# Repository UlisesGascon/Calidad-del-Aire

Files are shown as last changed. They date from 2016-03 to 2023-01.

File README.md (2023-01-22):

<h2 align="center">:warning: This repository is not longer maintained :warning:</h2>

# Calidad-del-Aire
Sistema para controlar la calidad del aire usando Arduino y los sensores MQ(2-9, y 135), AM2302 y DHT22. Los datos se exportan en formato .json vía comunicación serial

### Ejemplos de uso

- **[Calidad del Aire con Firebase](https://github.com/UlisesGascon/Calidad-del-Aire-con-Firebase)**
Repositorio que muestra como se pueden exportar estos datos usando Node.js para posteriormente almacenarlos en Firebase. Múltiples usuarios pueden consultar los datos en tiempo real usando Websockets. [Demo](https://calidaddelaire.firebaseio.com/)

### Contenedor (caja)

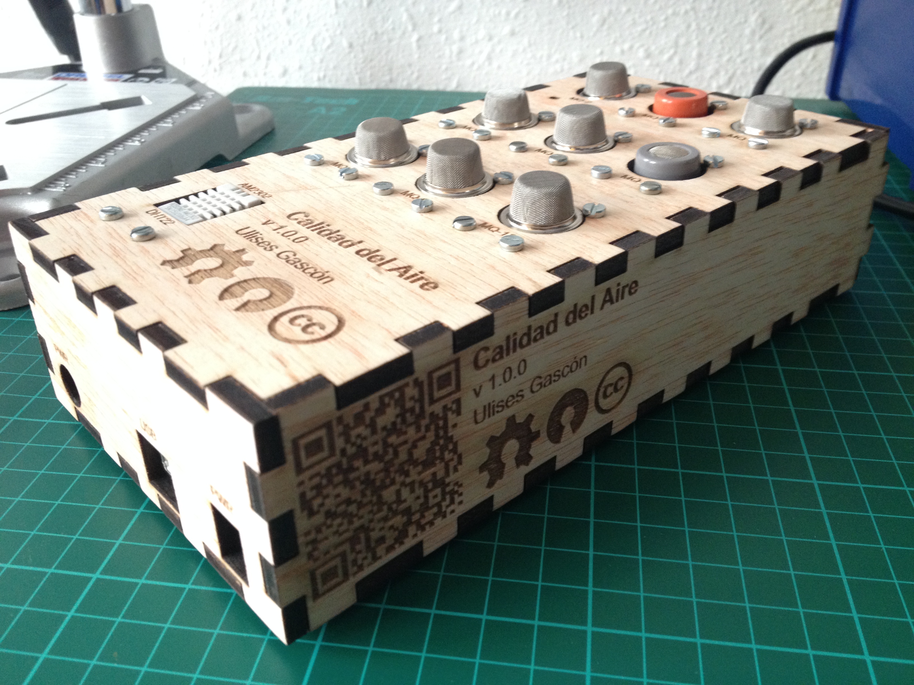
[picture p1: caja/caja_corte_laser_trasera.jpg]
caja


**Diseño impresión 3D**

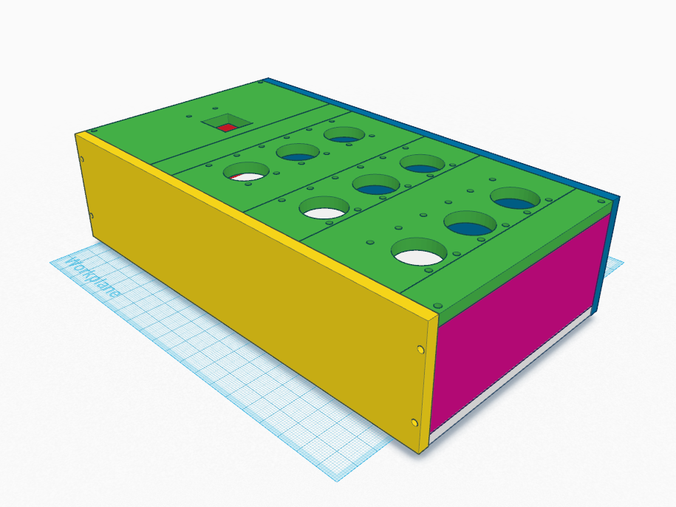
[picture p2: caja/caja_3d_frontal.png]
caja


- [Formato .STL](caja/caja_design.png)
- [Formato .OBJ](caja/caja_design.png)

**Diseño Corte Laser**

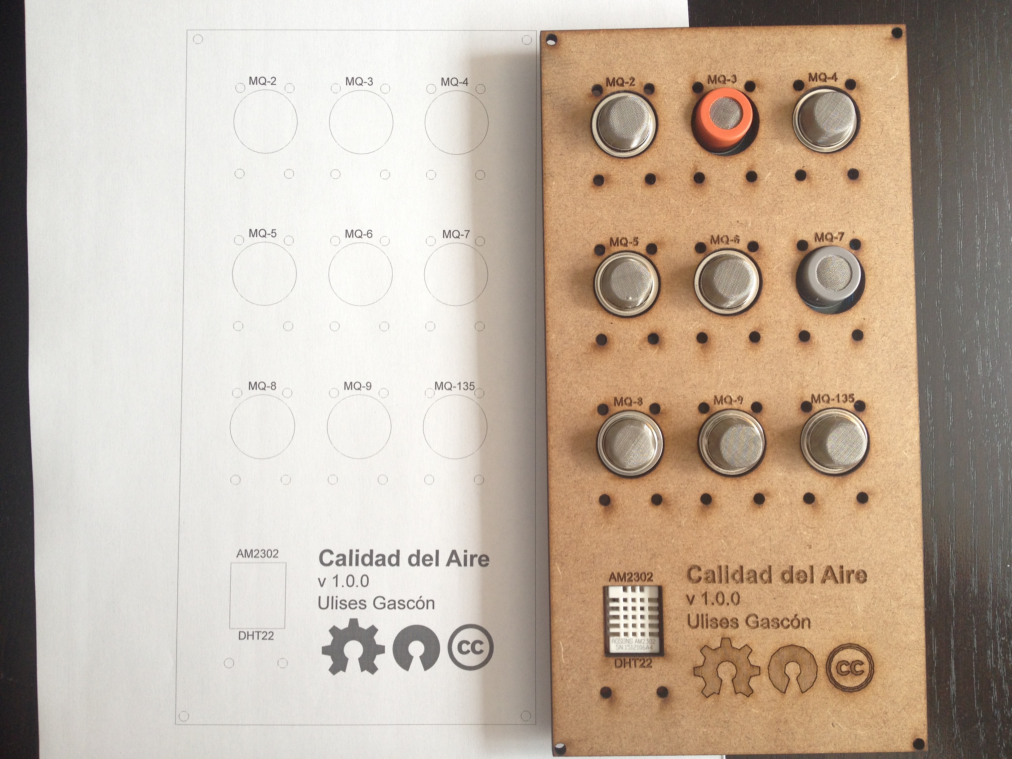
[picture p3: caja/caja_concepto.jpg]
caja


- [Formato .DXF](caja/caja_design.dxf)
- [Formato .SVG](caja/caja_design.svg)
- [Formato .PNG](caja/caja_design.png)
- [Formato .PDF](caja/caja_design.pdf)

### Conexiones

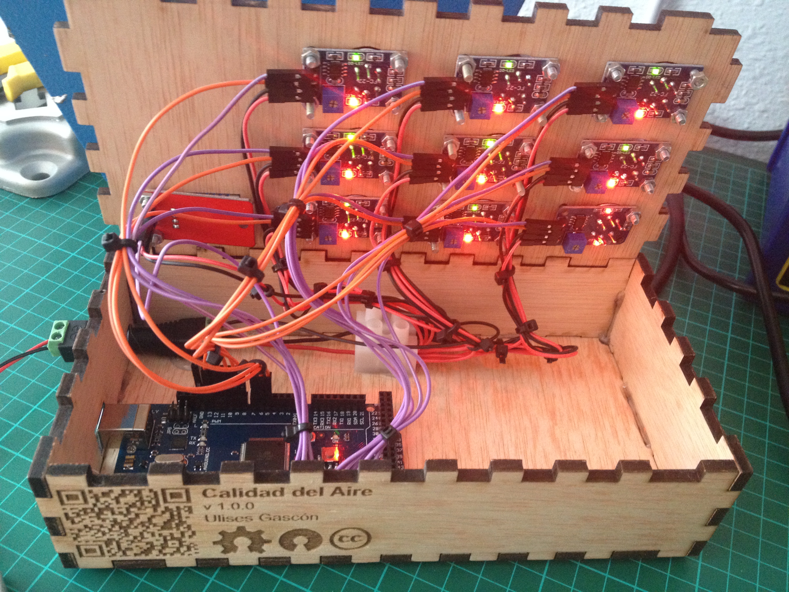
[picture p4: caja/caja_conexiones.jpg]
caja


**Alimentación**

- Alimentación externa (5v - 3A). Todos los sensores se conectan a la alimentación externa.

- GND del Arduino y GND de la fuente externa se conectan entre sí.

- IMPORTANTE: 5v (fuente de alimentación) y 5v (Arduino) NO se conectan entre sí.

**Analógicas**

- MQ-2 -> A13
- MQ-3 -> A12
- MQ-4 -> A11
- MQ-5 -> A10
- MQ-6 -> A9
- MQ-7 -> A8
- MQ-8 -> A7
- MQ-9 -> A6
- MQ-135 -> A5

**Digitales**

- MQ-2 -> 13
- MQ-3 -> 12
- MQ-4 -> 11
- MQ-5 -> 10
- MQ-6 -> 9
- MQ-7 -> 8
- MQ-8 -> 7
- MQ-9 -> 6
- MQ-135 -> 5
- AM2302/DHT22 -> 4

### Datos (formato [JSON](https://www.wikiwand.com/es/JSON))

Ejemplo de los datos que esperamos recibir vía puerto serial

```json
{
	"amoniaco": {
		"valido": true,
		"valor": 0.06,
		"unidad": "ppm",
		"descripcion": "Amoníaco",
		"formulaQuimica": ["NH3"],
		"umbralAlcanzado": false,
		"voltaje": 0.23,
		"resistencia": 20312.50,
		"valorAnalogico": 48,
		"sensor": "MQ-135"
	},
	"dioxidoDeCarbono": {
		"valido": true,
		"valor": 0.06,
		"unidad": "ppm",
		"descripcion": "Dióxido de carbono",
		"formulaQuimica": ["CO2"],
		"umbralAlcanzado": false,
		"voltaje": 0.23,
		"resistencia": 20312.50,
		"valorAnalogico": 48,
		"sensor": "MQ-135"
	},
	"oxidosDeNitrogeno": {
		"valido": true,
		"valor": 0.06,
		"unidad": "ppm",
		"descripcion": "Óxidos de nitrógeno (Óxido nitroso, Óxido nítrico, Anhídrido nitroso, Tetraóxido de nitrógeno, Peróxido nítrico, Anhídrido nítrico)",
		"formulaQuimica": ["NOx", "N2O", "NO", "N2O3", "N2O4", "NO2", "N2O5"],
		"umbralAlcanzado": false,
		"voltaje": 0.23,
		"resistencia": 20312.50,
		"valorAnalogico": 48,
		"sensor": "MQ-135"
	},
	"hidrogeno": {
		"valido": true,
		"valor": 0.09,
		"unidad": "ppm",
		"descripcion": "Hidrógeno",
		"formulaQuimica": ["H2"],
		"umbralAlcanzado": false,
		"voltaje": 0.32,
		"resistencia": 14738.46,
		"valorAnalogico": 65,
		"sensor": "MQ-8"
	},
	"monoxidoDeCarbono": {
		"valido": true,
		"valor": 0.09,
		"unidad": "ppm",
		"descripcion": "Monóxido de Carbono",
		"formulaQuimica": ["CO"],
		"umbralAlcanzado": false,
		"voltaje": 0.31,
		"resistencia": 15238.09,
		"valorAnalogico": 63,
		"sensor": "MQ-7"
	},
	"propano": {
		"valido": true,
		"valor": 0.15,
		"unidad": "ppm",
		"descripcion": "Propano",
		"formulaQuimica": ["C3H8"],
		"umbralAlcanzado": false,
		"voltaje": 0.42,
		"resistencia": 10895.35,
		"valorAnalogico": 86,
		"sensor": "MQ-6"
	},
	"metano": {
		"valido": true,
		"valor": 0.09,
		"unidad": "ppm",
		"descripcion": "Gas natural, Metano",
		"formulaQuimica": ["CH4"],
		"umbralAlcanzado": false,
		"voltaje": 0.32,
		"resistencia": 14738.46,
		"valorAnalogico": 65,
		"sensor": "MQ-4"
	},
	"glp": {
		"valido": true,
		"valor": 0.09,
		"unidad": "ppm",
		"descripcion": "Gas licuado del petróleo (Propano, Butano, ambos)",
		"formulaQuimica": ["C3H8", "C4H10"],
		"umbralAlcanzado": 1,
		"voltaje": 0.31,
		"resistencia": 15238.09,
		"valorAnalogico": 63,
		"sensor": "MQ-2"
	},
	"alcohol": {
		"valido": true,
		"valor": 0.02,
		"unidad": "mg/L",
		"descripcion": "Alcohol (Benceno, Propano, Etanol, Metanol)",
		"formulaQuimica": ["C6H6", "C3H8", "C2H6O", "CH3OH"],
		"umbralAlcanzado": false,
		"voltaje": 0.11,
		"resistencia": 45500.00,
		"valorAnalogico": 22,
		"sensor": "MQ-3"
	},
	"humedad": {
		"valido": true,
		"valor": 56.60,
		"sensor": "AM2302",
		"unidad": "%"
	},
	"temperatura": {
		"valido": true,
		"valor": 24.20,
		"sensor": "DHT22",
		"unidad": "°C"
	}
}
```

### Librerías

- [DHTMaster](https://github.com/markruys/arduino-DHT)

### Datasheets

- [MQ-2](datasheets/MQ-2_datasheet.pdf)
- [MQ-3](datasheets/MQ-3_datasheet.pdf)
- [MQ-4](datasheets/MQ-4_datasheet.pdf)
- [MQ-5](datasheets/MQ-5_datasheet.pdf)
- [MQ-6](datasheets/MQ-6_datasheet.pdf)
- [MQ-7](datasheets/MQ-7_datasheet.pdf)
- [MQ-8](datasheets/MQ-8_datasheet.pdf)
- [MQ-9](datasheets/MQ-9_datasheet.pdf)
- [MQ-135](datasheets/MQ-135_datasheet.pdf)
- [DHT22 y AM2302](datasheets/DHT22_datasheet.pdf)

### Sensores

- **Gases**

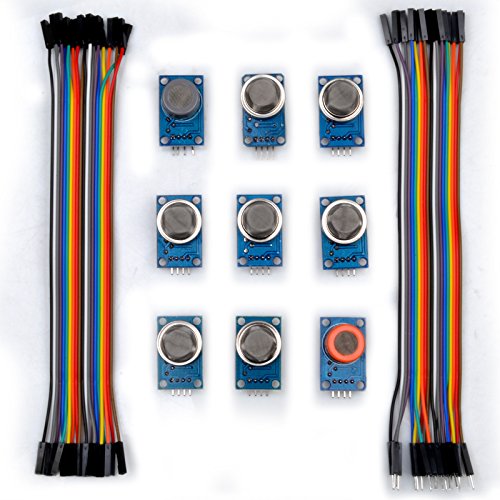
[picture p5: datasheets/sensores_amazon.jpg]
sensores_img


- [Sensor Kit (MQ2, MQ3, MQ4, MQ5, MQ6, MQ7, MQ8, MQ9 y MQ135) con jumpers](https://www.amazon.es/gp/product/B019GK4RNK)

- **Humedad y temperatura**

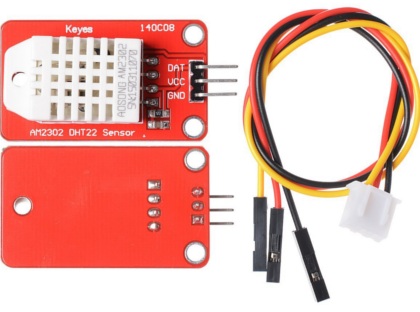
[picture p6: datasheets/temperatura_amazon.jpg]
temperatura_img


- [XCSOURCE® Módulo Sensor Digital Humedad DHT22 y Temperatura AM2302 Para Arduino TE248](https://www.amazon.es/gp/product/B011U8GA40/)

### Agradecimientos

- **[Trastejant - Sensores de gas](http://www.trastejant.es/tutoriales/electronica/sensoresGas.html)**
- **[Naylamp Mechatronics - Tutorial sensores de gas MQ2, MQ3, MQ7 y MQ135](http://www.naylampmechatronics.com/blog/42_Tutorial-sensores-de-gas-MQ2-MQ3-MQ7-y-MQ13.html)**

### Licencias

- Documentación bajo una [licencia de Creative Commons Reconocimiento-CompartirIgual 4.0 Internacional](http://creativecommons.org/licenses/by-sa/4.0/).
- Hardware (pendiente - v1.0.0)
- Software bajo una [licencia GPLv3](https://github.com/UlisesGascon/Calidad-del-Aire/blob/master/LICENSE)

 *Nota: En este proyecto se usan librerías (carpeta [/librerias](librerias)) de terceros y ejemplos (carpeta [/snippets](snippets)), estos no necesariamente están sujetos a la misma licencia que el resto del proyecto.*

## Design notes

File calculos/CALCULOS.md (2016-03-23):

# Cálculos

Estos son los calculos que se utilizan en el sketch para convertir los valores analógicos de los sensores.

### Alcohol

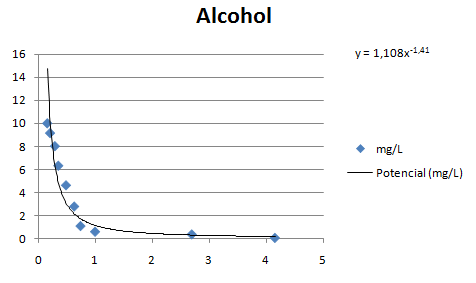
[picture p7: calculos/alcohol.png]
Alcohol


**Puntos de la curva**

Rs/Ro | mg/L
------------ | -------------
0,16 | 10
0,209 | 9,156
0,294 | 8,03
0,355 | 6,343
0,489 | 4,656
0,635 | 2,828
0,744 | 1,14
1 | 0,648
2,7 | 0,416
4,162 | 0,114

**Ecuación potencial**

- Expresión:
```
	y = 1,108x-1,41  
```
- Código:
```arduino
	double Alcohol = 1,108*pow(mq3_resistencia/5463, -1,41);
```

### Gases Licuados del Petróleo (GLP)

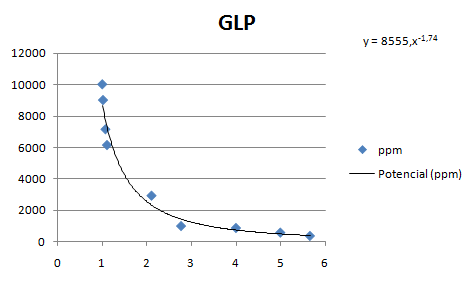
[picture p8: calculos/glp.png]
GLP


**Puntos de la curva**

Rs/Ro | ppm
------------ | -------------
0,992 | 10000
1,01 | 9000
1,064 | 7142,85
1,1 | 6142,85
2,1 | 2928,57
2,766 | 1000
4 | 878,57
5 | 585,71
5,666 | 371,42

**Ecuación potencial**

- Expresión:
```
	y = 8555,x-1,74
```
- Código:
```arduino
	double glp = 8555*pow(mq2_resistencia/5463, -1,74);
```

### Metano

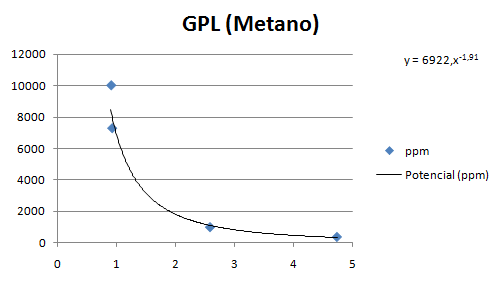
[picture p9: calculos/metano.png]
Metano


**Puntos de la curva**

Rs/Ro | ppm
------------ | -------------
0,898 | 10000
0,915 | 7279,069
2,583 | 1000
4,75 | 379,069

**Ecuación potencial**

- Expresión:
```
	y = 6922,x-1,91
```
- Código:
```arduino
	double metano = 6922*pow(mq4_resistencia/5463, -1,91);
```

### Propano

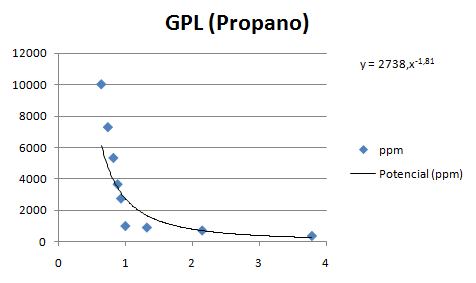
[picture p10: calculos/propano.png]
propano


**Puntos de la curva**

Rs/Ro | ppm
------------ | -------------
0,64 | 10000
0,738 | 7279,069
0,82 | 5325,581
0,885 | 3651,162
0,934 | 2744,186
1 | 1000
1,32 | 903,076
2,145 | 716,153
3,781 | 370

**Ecuación potencial**

- Expresión:
```
	y = 2738,x-1,81 
```
- Código:
```arduino
	double propano = 2738*pow(mq6_resistencia/5463, -1,81);
```

### Monóxido de Carbono

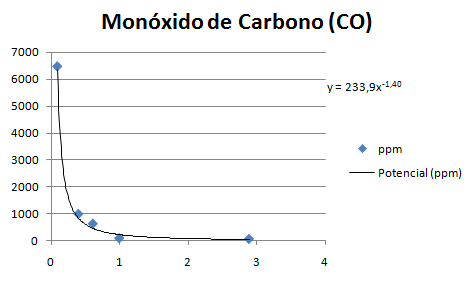
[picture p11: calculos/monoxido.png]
monoxido


**Puntos de la curva**

Rs/Ro | ppm
------------ | -------------
0,096 | 6464,285
0,405 | 1000
0,614 | 640
1 | 100
2,894 | 73,214

**Ecuación potencial**

- Expresión:
```
	y = 233,9x-1,40 
```
- Código:
```arduino
	double monoxidoDeCarbono = 233,9*pow(mq7_resistencia/5463, -1,40);
```

### Hidrógeno

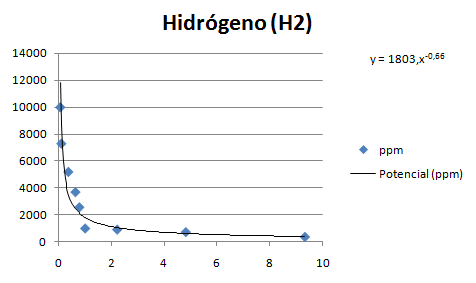
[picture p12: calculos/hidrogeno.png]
hidrogeno


**Puntos de la curva**

Rs/Ro | ppm
------------ | -------------
0,059 | 10000
0,1 | 7300
0,366 | 5200
0,633 | 3700
0,783 | 2575
1 | 1000
2,211 | 917,5
4,807 | 730
9,307 | 370

**Ecuación potencial**

- Expresión:
```
	y = 1803,x-0,66 
```
- Código:
```arduino
	double hidrogeno = 1803*pow(mq8_resistencia/5463, -0.66);
```

### Dióxido de Carbono

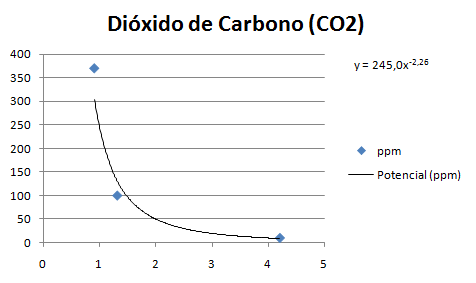
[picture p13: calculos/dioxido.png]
dioxido


**Puntos de la curva**

Rs/Ro | ppm
------------ | -------------
0,911 | 370
1,321 | 100
4,214 | 10

**Ecuación potencial**

- Expresión:
```
	y = 245,0x-2,26
```
- Código:
```arduino
	double dioxidoDeCarbono = 245*pow(mq135_resistencia/5463, -2.26);
```

### Óxidos de Nitrógeno

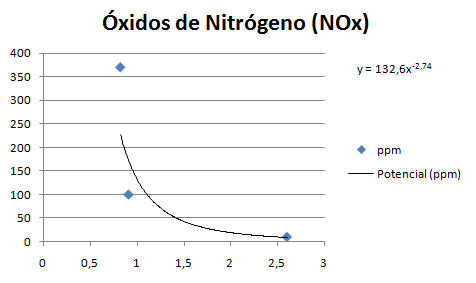
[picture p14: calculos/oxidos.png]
oxidos


**Puntos de la curva**

Rs/Ro | ppm
------------ | -------------
0,823 | 370
0,911 | 100
2,607 | 10

**Ecuación potencial**

- Expresión:
```
	y = 132,6x-2,74 
```
- Código:
```arduino
	double oxidosDeNitrogeno = 132.6*pow(mq135_resistencia/5463, -2,74);
```

### Amoniaco

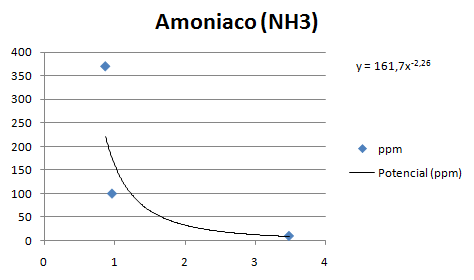
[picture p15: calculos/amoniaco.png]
amoniaco


**Puntos de la curva**

Rs/Ro | ppm
------------ | -------------
0,871 | 370
0,967 | 100
3,491 | 10

**Ecuación potencial**

- Expresión:
```
	y = 161,7x-2,26 
```
- Código:
```arduino
	double amoniaco = 161,7*pow(mq135_resistencia/5463, -2,26);
```

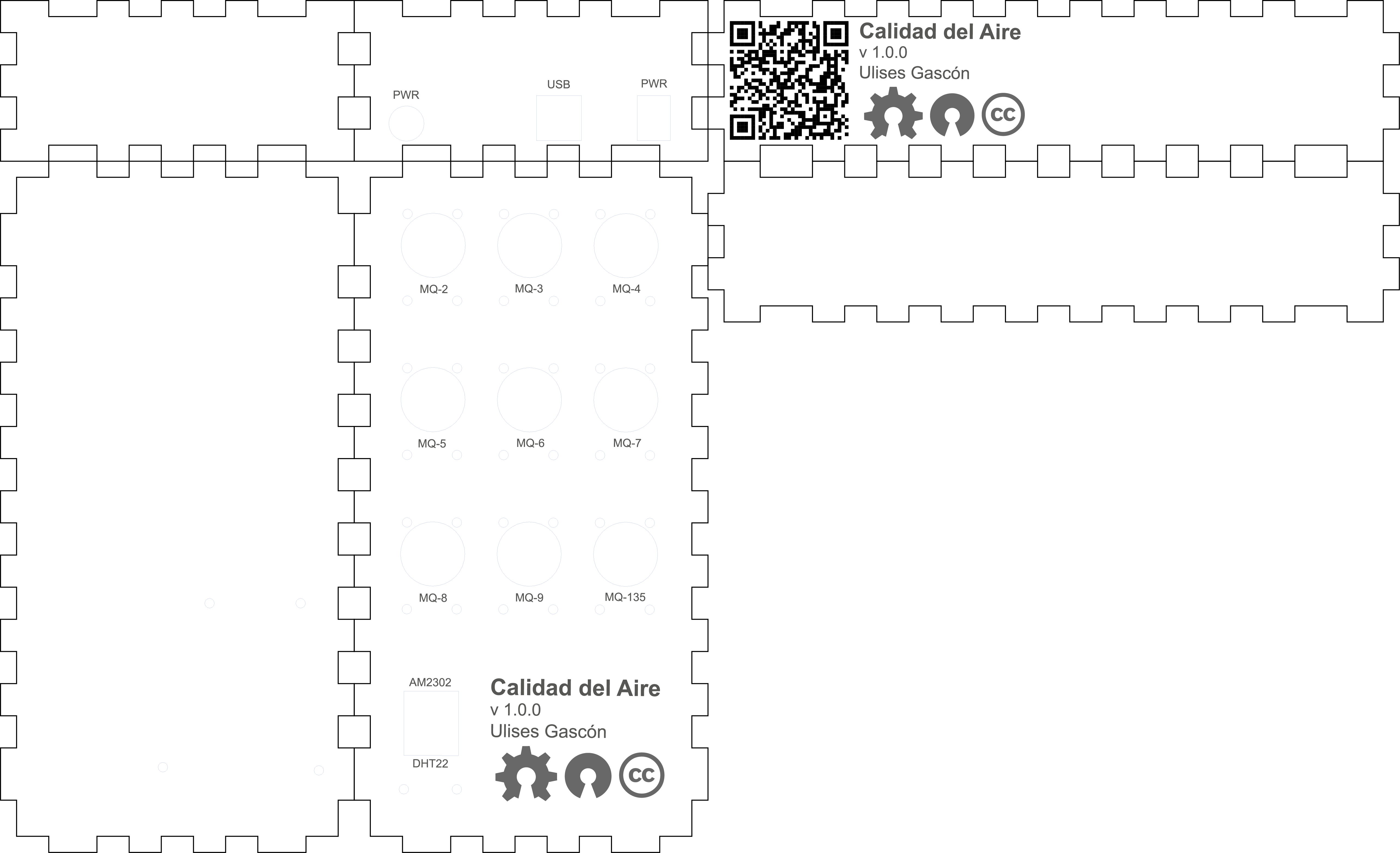
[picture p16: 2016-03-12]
caja/caja_design.png

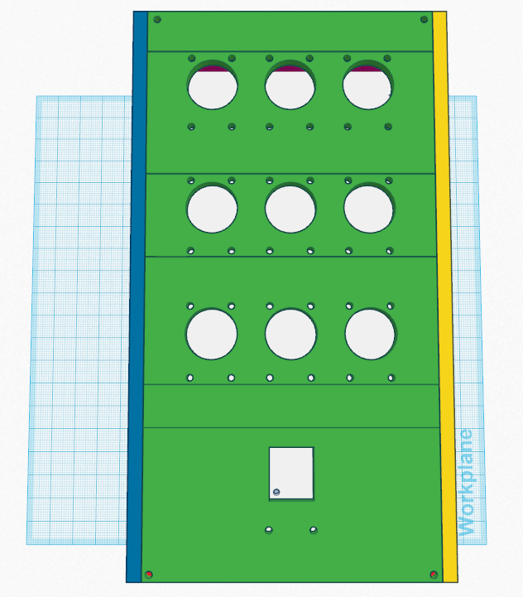
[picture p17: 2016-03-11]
caja/caja_3d_superior.png

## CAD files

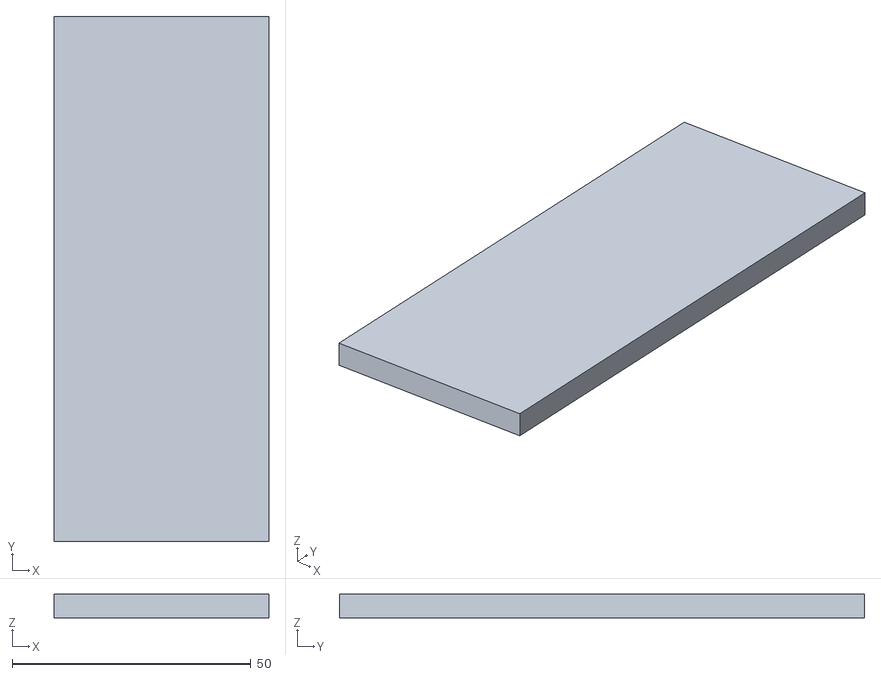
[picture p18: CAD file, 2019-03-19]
caja/caja_design (extracted) 5.stl
45.0 x 110.0 x 5.00

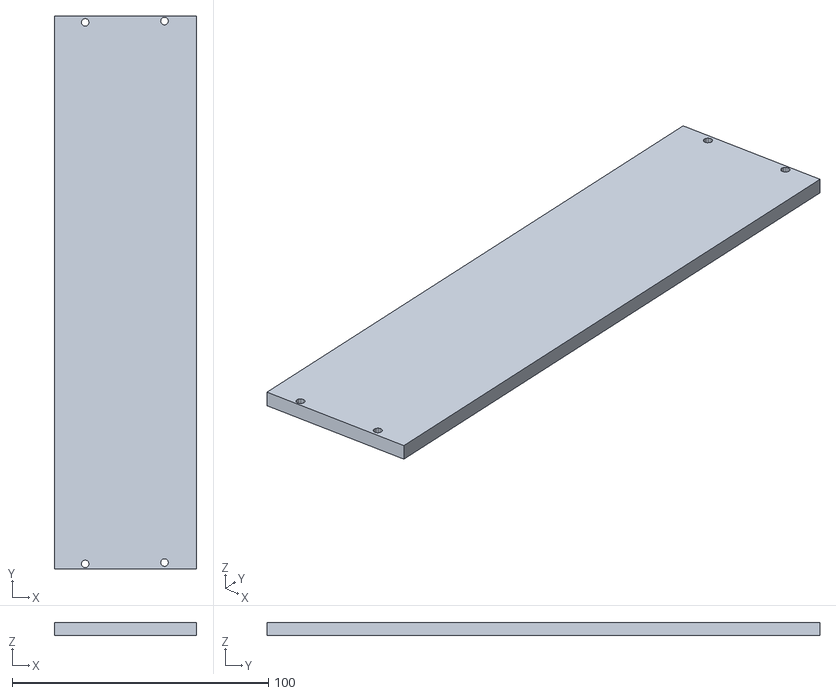
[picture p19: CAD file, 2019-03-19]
caja/caja_design (extracted) 1.stl
55.5 x 216.0 x 5.00

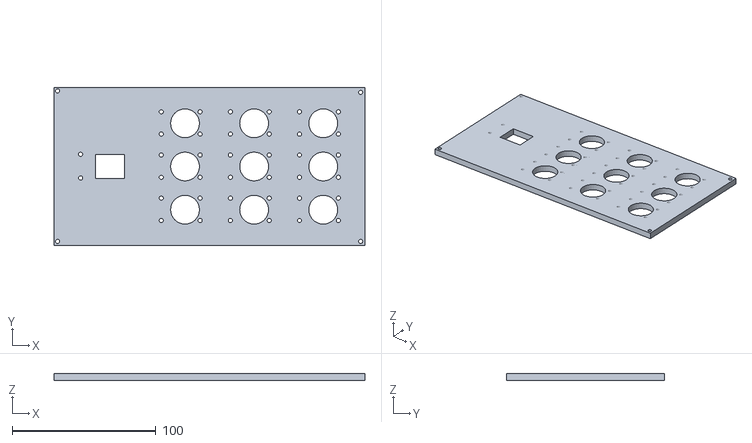
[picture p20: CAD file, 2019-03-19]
caja/caja_design (extracted) 3.stl
216.0 x 110.0 x 5.00

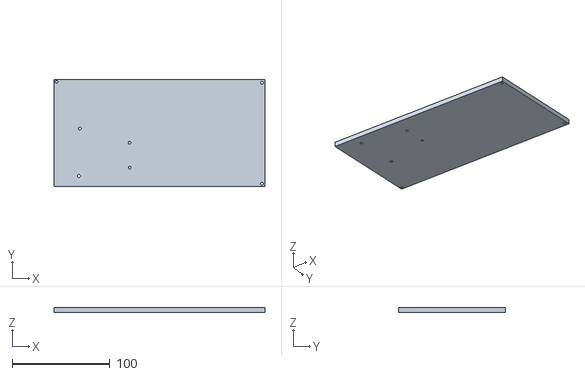
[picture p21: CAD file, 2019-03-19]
caja/caja_design (extracted) 4.stl
216.0 x 110.0 x 5.00

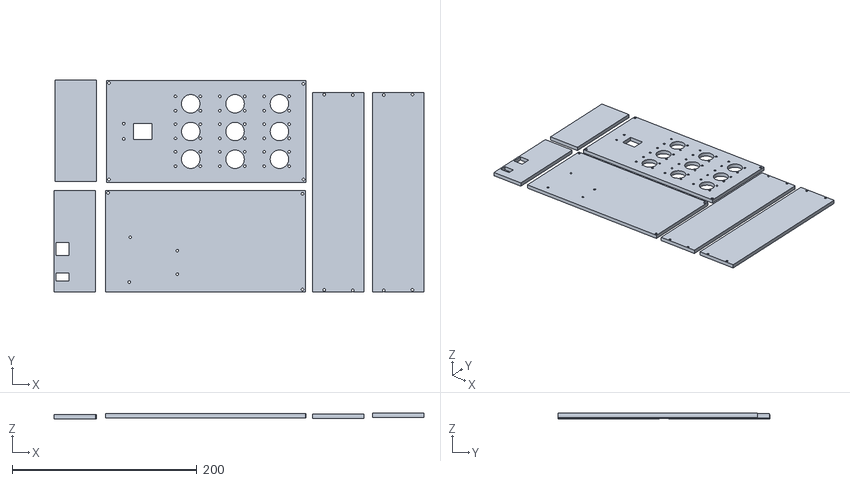
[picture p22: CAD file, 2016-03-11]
caja/caja_design.stl
400.5 x 230.0 x 6.75

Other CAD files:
caja/caja_design (extracted) 6.stl
caja/caja_design (extracted) 2.stl
caja/caja_design.dwg
caja/caja_design.dxf
caja/caja_design.obj

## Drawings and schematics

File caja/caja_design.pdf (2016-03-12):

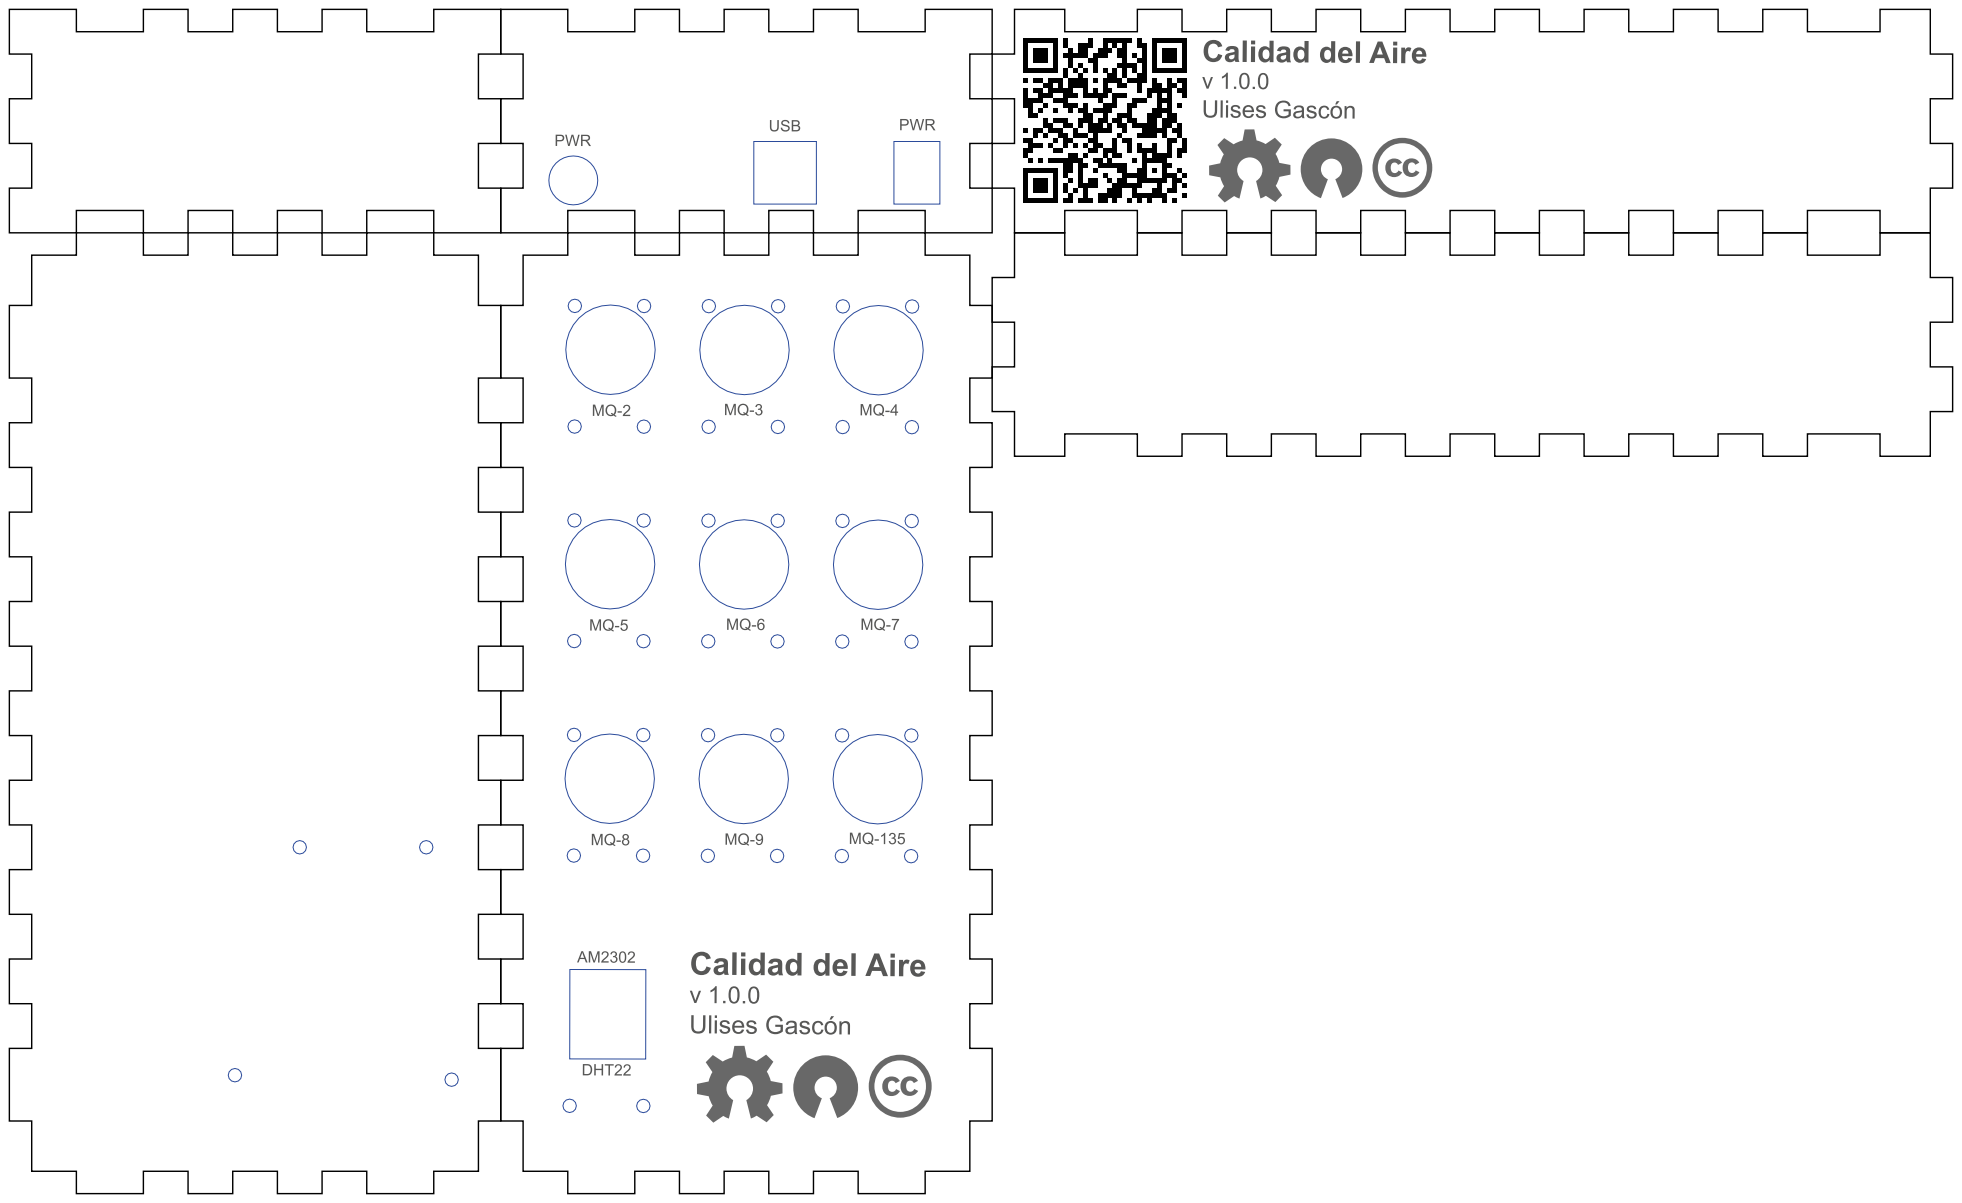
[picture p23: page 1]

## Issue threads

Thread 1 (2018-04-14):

Valores recomendados de mediciones

javifly, 2018-04-14:
Hola,

Queria construir este dispositivo para recoger los datos de mi pueblo y subirlos al ordenador.
¿Podrias indicarme cuales son los valores recomendados para cada una de las variables?
Es decir para una calidad de aire buena entre que rango debe estar cada uno de esos valores: Amonico, Alcohol, metano... etc...

Gracias

UlisesGascon, 2019-04-15:
Pues... justo ese es un problema bastante extendido. Es dificil saber el umbral de trabajo en cada municipio, porque en muchas ocasiones es necesario tener varias lecturas a lo largo de un día para saber si sobrepasamos el límite. Yo por ahora estoy usando la propia resistencia con valores "aleatorios (pero altos)"

Closed 2019-04-15.

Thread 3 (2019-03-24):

en el cod no lees los 9 sensores que tienes en la caja

javifly, 2019-03-24:
No se si me equivoco pero en tu archivo de codigo no veo que leas mas que 7 sensores mientras que en la caja tienes 9. ¿Como puede ser eso?

¿Por otro lado la fuente de 5V 3A está medida bien?¿O sirve con una de 2A?

Saludos, gracias

javifly, 2019-03-24:
No lees el MQ-5 ni el MQ-9 ¿por que?

UlisesGascon, 2019-04-15:
Hola @javifly. Creo recordar que los sensores MQ-5 y MQ-9 median datos similares a otros sensores ya incluidos en la caja y para simplificar la lectura decidí omitirlos del JSON resultante, pero estan instalados y se pueden utilizar. La fuente de alimentación que uso es una reciclada, pero creo que con 2A también debería de funcionar. En [las especificaciones](https://github.com/UlisesGascon/Calidad-del-Aire/tree/master/datasheets) tienes los consumos relativos.

javifly, 2019-04-23:
ok, si con un de 2A debería ser suficiente según mis cálculos si...

Según he visto los sensores son:
// MQ-2 / GasLicuadoDelPetroleo / glp // ppm (<1 ppm) (60% C3H8 y 40% C4H10)
// MQ-3 / Alcohol / alcohol // ppm (¿¿¿<1 ppm???) (C2H6O)
// MQ-4 / Metano / metano // ppm (<1.5 ppm) (CH4)
// MQ-5 / Gas natural / gnatural // ¿nose1?
// MQ-6 / Propano / propano // ppm (<1 ppm) (C3H8)
// MQ-7 / MonoxidoDeCarbono / monoxidoDeCarbono // ppm (<1 ppm) (CO)
// MQ-8 / Hidrogeno / hidrogeno // ppm (<0.5 ppm) (H)
// MQ-9 / Monóxido de carbono / moncarb // ¿nose2?
 // MQ-135 / DioxidoDeCarbono / dioxidoDeCarbono // ppm (310-330 ppm) (CO2)
 // MQ-135 / OxidosDeNitrogeno / oxidosDeNitrogeno // ppm (0.001-0.01 ppm) (NO)
 // MQ-135 / Amoniaco / amoniaco // ppm (<0.015 ppm) (NH3)

Vamos que creo que miden:
MQ-5 Sensor de Gas Propano
MQ-9 Sensor de Gas Monóxido de Carbono

Y ningún otro sensor miden lo que MQ5 y MQ9, ¿no?

¿Me ayudarias con la recopilacion de datos de estos 2 sensores?

javifly, 2020-01-26:
Efectivamente MQ7 y MQ9 miden lo mismo.
Pero que mida lo mismo que MQ5 no veo...

AnizCoronel, 2020-04-13:
¿Tienes algún diagrama de conexión del sistema completo?
¿O puedes mostrar la conexión de la fuente de poder con los sensores y el arduino?

UlisesGascon, 2020-04-13:
[Este](https://github.com/UlisesGascon/Calidad-del-Aire#conexiones) es el mejor esquema de conexiones que tengo, puedes usar la foto como guía ;-)

Closed 2020-04-13.

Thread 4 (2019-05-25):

Duda presupuestaria

Punksolid, 2019-05-25:
Hola, ando desarrollando un frontend para la interpretación de datos de la calidad del aire y estaba considerando talvez en hacer un dispositivo.
Cuanto invertiste aproximadamente en el proyecto?
Qué desventaja tiene tu dispositivo comparado con los productos comerciales que están a la venta?

Saludos y felicidades por la documentación.

UlisesGascon, 2019-05-31:
Hola @Punksolid !

En su momento creo que me costo entorno a los 50-100€ entre materiales, sensores, alquiler de corte laser, etc... y todas las pruebas que fui sacando hasta que di con la versión final.

Creo que algunos productos comerciales ya tienen sensores más afinados y específicos aunque son mucho menos DYI. :-)

Closed 2019-05-31.

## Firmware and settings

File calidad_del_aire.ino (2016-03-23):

// Version 1.0.0 - Development

#include "DHT.h"

DHT dht;

void setup()
{
  Serial.begin(9600);
  dht.setup(4);
  pinMode(5, INPUT);
  pinMode(6, INPUT);
  pinMode(7, INPUT);
  pinMode(8, INPUT);
  pinMode(9, INPUT);
  pinMode(10, INPUT);
  pinMode(11, INPUT);
  pinMode(12, INPUT);
  pinMode(13, INPUT);
}

void loop()
{
  // Ritmo Refresco;
  delay(1000);

  // DHT22 y AM2302
  float humedad = dht.getHumidity();
  float temperatura = dht.getTemperature();
 
  // MQ-2
  int mq2_adc = analogRead(A13);
  float mq2_voltaje = mq2_adc * (5.0 / 1023.0);
  float mq2_resistencia = 1000*((5-mq2_voltaje)/mq2_voltaje);
  double glp = 8555*pow(mq2_resistencia/5463, -1.74);
  bool mq2_umbral = digitalRead(13); 

  // MQ-3
  int mq3_adc = analogRead(A12);
  float mq3_voltaje = mq3_adc * (5.0 / 1023.0);
  float mq3_resistencia = 1000*((5-mq3_voltaje)/mq3_voltaje); 
  double alcohol = 1.108*pow(mq3_resistencia/5463, -1.41);
  String mq3_umbral = "false";

  if(digitalRead(12) == 0){
    mq3_umbral = "true";
  }

  // MQ-4
  int mq4_adc = analogRead(A11);
  float mq4_voltaje = mq4_adc * (5.0 / 1023.0);
  float mq4_resistencia = 1000*((5-mq4_voltaje)/mq4_voltaje);
  double metano = 6922*pow(mq4_resistencia/5463, -1.91);
  String mq4_umbral = "false";

  if(digitalRead(11) == 0){
    mq4_umbral = "true";
  }

  // MQ-6
  int mq6_adc = analogRead(A9);
  float mq6_voltaje = mq6_adc * (5.0 / 1023.0);
  float mq6_resistencia = 1000*((5-mq6_voltaje)/mq6_voltaje);
  double propano = 2738*pow(mq6_resistencia/5463, -1.81);
  String mq6_umbral = "false";

  if(digitalRead(9) == 0){
    mq6_umbral = "true";
  }

  // MQ-7
  int mq7_adc = analogRead(A8);
  float mq7_voltaje = mq7_adc * (5.0 / 1023.0);
  float mq7_resistencia = 1000*((5-mq7_voltaje)/mq7_voltaje);
  double monoxidoDeCarbono = 233.9*pow(mq7_resistencia/5463, -1.40);
  String mq7_umbral = "false";

  if(digitalRead(8) == 0){
    mq7_umbral = "true";
  }

  // MQ-8
  int mq8_adc = analogRead(A7);
  float mq8_voltaje = mq8_adc * (5.0 / 1023.0);
  float mq8_resistencia = 1000*((5-mq8_voltaje)/mq8_voltaje);
  double hidrogeno = 1803*pow(mq8_resistencia/5463, -0.66);
  String mq8_umbral = "false";

  if(digitalRead(7) == 0){
    mq8_umbral = "true";
  }

  // MQ-135
  int mq135_adc = analogRead(A5);
  float mq135_voltaje = mq135_adc * (5.0 / 1023.0);
  float mq135_resistencia = 1000*((5-mq135_voltaje)/mq135_voltaje);
  double dioxidoDeCarbono = 245*pow(mq135_resistencia/5463, -2.26);
  double oxidosDeNitrogeno = 132.6*pow(mq135_resistencia/5463, -2.74);
  double amoniaco = 161.7*pow(mq135_resistencia/5463, -2.26);
  String mq135_umbral = "false";

  if(digitalRead(5) == 0){
    mq135_umbral = "true";
  }

  // JSON
  String jsonSerial = "{";

  // MQ-135
  if (isnan(dioxidoDeCarbono) || isnan(oxidosDeNitrogeno) || isnan(amoniaco)) {

    jsonSerial += "\"dioxidoDeCarbono\": {";
    jsonSerial += "\"valido\": false,";
    jsonSerial += "\"error\": \"Valor númerico no valido\"";
    jsonSerial += "},";

    jsonSerial += "\"oxidosDeNitrogeno\": {";
    jsonSerial += "\"valido\": false,";
    jsonSerial += "\"error\": \"Valor númerico no valido\"";
    jsonSerial += "},";

    jsonSerial += "\"amoniaco\": {";
    jsonSerial += "\"valido\": false,";
    jsonSerial += "\"error\": \"Valor númerico no valido\"";
    jsonSerial += "},";

  } else {

    jsonSerial += "\"amoniaco\": {";
    jsonSerial += "\"valido\": true,";
    jsonSerial += "\"valor\":"; 
    jsonSerial += amoniaco;
    jsonSerial += ",\"unidad\": \"ppm\",";
    jsonSerial += "\"descripcion\": \"Amoníaco\",";      
    jsonSerial += "\"formulaQuimica\": [\"NH3\"],";    
    jsonSerial += "\"umbralAlcanzado\": ";
    jsonSerial += mq135_umbral;
    jsonSerial += ",\"voltaje\": ";
    jsonSerial += mq135_voltaje;
    jsonSerial += ",\"resistencia\":";
    jsonSerial += mq135_resistencia;
    jsonSerial += ",\"valorAnalogico\":";
    jsonSerial += mq135_adc;
    jsonSerial += ",\"sensor\": \"MQ-135\"";
    jsonSerial += "},";

    jsonSerial += "\"dioxidoDeCarbono\": {";
    jsonSerial += "\"valido\": true,";
    jsonSerial += "\"valor\":"; 
    jsonSerial += dioxidoDeCarbono;
    jsonSerial += ",\"unidad\": \"ppm\",";
    jsonSerial += "\"descripcion\": \"Dióxido de carbono\",";      
    jsonSerial += "\"formulaQuimica\": [\"CO2\"],";    
    jsonSerial += "\"umbralAlcanzado\": ";
    jsonSerial += mq135_umbral;
    jsonSerial += ",\"voltaje\": ";
    jsonSerial += mq135_voltaje;
    jsonSerial += ",\"resistencia\":";
    jsonSerial += mq135_resistencia;
    jsonSerial += ",\"valorAnalogico\":";
    jsonSerial += mq135_adc;
    jsonSerial += ",\"sensor\": \"MQ-135\"";
    jsonSerial += "},";  

    jsonSerial += "\"oxidosDeNitrogeno\": {";
    jsonSerial += "\"valido\": true,";
    jsonSerial += "\"valor\":"; 
    jsonSerial += oxidosDeNitrogeno;
    jsonSerial += ",\"unidad\": \"ppm\",";
    jsonSerial += "\"descripcion\": \"Óxidos de nitrógeno (Óxido nitroso, Óxido nítrico, Anhídrido nitroso, Tetraóxido de nitrógeno, Peróxido nítrico, Anhídrido nítrico)\",";      
    jsonSerial += "\"formulaQuimica\": [\"NOx\", \"N2O\", \"NO\", \"N2O3\", \"N2O4\", \"NO2\", \"N2O5\"],";    
    jsonSerial += "\"umbralAlcanzado\": ";
    jsonSerial += mq135_umbral;
    jsonSerial += ",\"voltaje\": ";
    jsonSerial += mq135_voltaje;
    jsonSerial += ",\"resistencia\":";
    jsonSerial += mq135_resistencia;
    jsonSerial += ",\"valorAnalogico\":";
    jsonSerial += mq135_adc;
    jsonSerial += ",\"sensor\": \"MQ-135\"";
    jsonSerial += "},"; 

  }

  // MQ-8
  if (isnan(hidrogeno)) {

    jsonSerial += "\"hidrogeno\": {";
    jsonSerial += "\"valido\": false,";
    jsonSerial += "\"error\": \"Valor númerico no valido\"";
    jsonSerial += "},";

  } else {

    jsonSerial += "\"hidrogeno\": {";
    jsonSerial += "\"valido\": true,";
    jsonSerial += "\"valor\":"; 
    jsonSerial += hidrogeno;
    jsonSerial += ",\"unidad\": \"ppm\",";
    jsonSerial += "\"descripcion\": \"Hidrógeno\",";      
    jsonSerial += "\"formulaQuimica\": [\"H2\"],";    
    jsonSerial += "\"umbralAlcanzado\": ";
    jsonSerial += mq8_umbral;
    jsonSerial += ",\"voltaje\": ";
    jsonSerial += mq8_voltaje;
    jsonSerial += ",\"resistencia\":";
    jsonSerial += mq8_resistencia;
    jsonSerial += ",\"valorAnalogico\":";
    jsonSerial += mq8_adc;
    jsonSerial += ",\"sensor\": \"MQ-8\"";
    jsonSerial += "},";  

  }

  // MQ-7
  if (isnan(monoxidoDeCarbono)) {

    jsonSerial += "\"monoxidoDeCarbono\": {";
    jsonSerial += "\"valido\": false,";
    jsonSerial += "\"error\": \"Valor númerico no valido\"";
    jsonSerial += "},";

  } else {

    jsonSerial += "\"monoxidoDeCarbono\": {";
    jsonSerial += "\"valido\": true,";
    jsonSerial += "\"valor\":"; 
    jsonSerial += monoxidoDeCarbono;
    jsonSerial += ",\"unidad\": \"ppm\",";
    jsonSerial += "\"descripcion\": \"Monóxido de Carbono\",";      
    jsonSerial += "\"formulaQuimica\": [\"CO\"],";    
    jsonSerial += "\"umbralAlcanzado\": ";
    jsonSerial += mq7_umbral;
    jsonSerial += ",\"voltaje\": ";
    jsonSerial += mq7_voltaje;
    jsonSerial += ",\"resistencia\":";
    jsonSerial += mq7_resistencia;
    jsonSerial += ",\"valorAnalogico\":";
    jsonSerial += mq7_adc;
    jsonSerial += ",\"sensor\": \"MQ-7\"";
    jsonSerial += "},";

  }

  // MQ-6
  if (isnan(propano)) {

    jsonSerial += "\"propano\": {";
    jsonSerial += "\"valido\": false,";
    jsonSerial += "\"error\": \"Valor númerico no valido\"";
    jsonSerial += "},";

  } else {

    jsonSerial += "\"propano\": {";
    jsonSerial += "\"valido\": true,";
    jsonSerial += "\"valor\":"; 
    jsonSerial += propano;
    jsonSerial += ",\"unidad\": \"ppm\",";
    jsonSerial += "\"descripcion\": \"Propano\",";      
    jsonSerial += "\"formulaQuimica\": [\"C3H8\"],";    
    jsonSerial += "\"umbralAlcanzado\": ";
    jsonSerial += mq6_umbral;
    jsonSerial += ",\"voltaje\": ";
    jsonSerial += mq6_voltaje;
    jsonSerial += ",\"resistencia\":";
    jsonSerial += mq6_resistencia;
    jsonSerial += ",\"valorAnalogico\":";
    jsonSerial += mq6_adc;
    jsonSerial += ",\"sensor\": \"MQ-6\"";
    jsonSerial += "},";

  }

  // MQ-4
  if (isnan(metano)) {

    jsonSerial += "\"metano\": {";
    jsonSerial += "\"valido\": false,";
    jsonSerial += "\"error\": \"Valor númerico no valido\"";
    jsonSerial += "},";

  } else {

    jsonSerial += "\"metano\": {";
    jsonSerial += "\"valido\": true,";
    jsonSerial += "\"valor\":"; 
    jsonSerial += metano;
    jsonSerial += ",\"unidad\": \"ppm\",";
    jsonSerial += "\"descripcion\": \"Gas natural, Metano\",";      
    jsonSerial += "\"formulaQuimica\": [\"CH4\"],";    
    jsonSerial += "\"umbralAlcanzado\": ";
    jsonSerial += mq4_umbral;
    jsonSerial += ",\"voltaje\": ";
    jsonSerial += mq4_voltaje;
    jsonSerial += ",\"resistencia\":";
    jsonSerial += mq4_resistencia;
    jsonSerial += ",\"valorAnalogico\":";
    jsonSerial += mq4_adc;
    jsonSerial += ",\"sensor\": \"MQ-4\"";
    jsonSerial += "},"; 

  }

  // MQ-2
  if (isnan(glp)) {
    
    jsonSerial += "\"glp\": {";
    jsonSerial += "\"valido\": false,";
    jsonSerial += "\"error\": \"Valor númerico no valido\"";
    jsonSerial += "},";
  
  } else {

    jsonSerial += "\"glp\": {";
    jsonSerial += "\"valido\": true,";
    jsonSerial += "\"valor\":"; 
    jsonSerial += glp;
    jsonSerial += ",\"unidad\": \"ppm\",";
    jsonSerial += "\"descripcion\": \"Gas licuado del petróleo (Propano, Butano, ambos)\",";      
    jsonSerial += "\"formulaQuimica\": [\"C3H8\", \"C4H10\"],";    
    jsonSerial += "\"umbralAlcanzado\": ";
    jsonSerial += mq2_umbral;
    jsonSerial += ",\"voltaje\": ";
    jsonSerial += mq2_voltaje;
    jsonSerial += ",\"resistencia\":";
    jsonSerial += mq2_resistencia;
    jsonSerial += ",\"valorAnalogico\":";
    jsonSerial += mq2_adc;
    jsonSerial += ",\"sensor\": \"MQ-2\"";
    jsonSerial += "},";  

  }

  if (isnan(alcohol)) {
  
    jsonSerial += "\"alcohol\": {";
    jsonSerial += "\"valido\": false,";
    jsonSerial += "\"error\": \"Valor númerico no valido\"";
    jsonSerial += "},";
  
  } else {

    jsonSerial += "\"alcohol\": {";
    jsonSerial += "\"valido\": true,";
    jsonSerial += "\"valor\":"; 
    jsonSerial += alcohol;
    jsonSerial += ",\"unidad\": \"mg/L\",";
    jsonSerial += "\"descripcion\": \"Alcohol (Benceno, Propano, Etanol, Metanol)\",";      
    jsonSerial += "\"formulaQuimica\": [\"C6H6\", \"C3H8\", \"C2H6O\", \"CH3OH\"],";    
    jsonSerial += "\"umbralAlcanzado\": ";
    jsonSerial += mq3_umbral;
    jsonSerial += ",\"voltaje\": ";
    jsonSerial += mq3_voltaje;
    jsonSerial += ",\"resistencia\":";
    jsonSerial += mq3_resistencia;
    jsonSerial += ",\"valorAnalogico\":";
    jsonSerial += mq3_adc;
    jsonSerial += ",\"sensor\": \"MQ-3\"";
    jsonSerial += "},";     

  }
  
  // Temperatura y Humedad (DHT22, AM2302)
  if (isnan(temperatura) || isnan(humedad)) {

    jsonSerial += "\"humedad\": {";
    jsonSerial += "\"valido\": false,";
    jsonSerial += "\"error\": \"Valor númerico no valido\"";
    jsonSerial += "},";
    jsonSerial += "\"temperatura\": {";
    jsonSerial += "\"valido\": false,";
    jsonSerial += "\"error\": \"Valor númerico no valido\"";   
    jsonSerial += "}";

  } else {

    jsonSerial += "\"humedad\": {";
    jsonSerial += "\"valido\": true,";
    jsonSerial += "\"valor\":";
    jsonSerial += humedad;
    jsonSerial += ",\"sensor\": \"AM2302\",";
    jsonSerial += "\"unidad\": \"%\"";  
    jsonSerial += "},";
    
    jsonSerial += "\"temperatura\": {";
    jsonSerial += "\"valido\": true,";
    jsonSerial += "\"valor\":";
    jsonSerial += temperatura;
    jsonSerial += ",\"sensor\": \"DHT22\",";
    jsonSerial += "\"unidad\": \"°C\"";    
    jsonSerial += "}";    
      
  }

  jsonSerial += "}";

  // Impresión
  Serial.println(jsonSerial);
}

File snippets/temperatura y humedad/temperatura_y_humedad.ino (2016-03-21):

#include "DHT.h"

DHT dht;

void setup()
{
  Serial.begin(9600);
  Serial.println("Empecemos...");
  dht.setup(4);
}

void loop()
{
  delay(dht.getMinimumSamplingPeriod());

  float humedad = dht.getHumidity();
  float temperatura = dht.getTemperature();
 

  if (isnan(temperatura) || isnan(humedad)) {
    Serial.println("Error en la lectura de datos.");
  } else {
    Serial.print("Humedad: ");
    Serial.print(humedad);
    Serial.print("%\t");
    Serial.print("Temperatura: ");
    Serial.print(temperatura);
    Serial.println("°C");
  }
}

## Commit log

2016-03-11 Archivos de la caja y documentación
    [caja_design.dxf, caja_design.obj, caja_design.stl]
2016-03-11 Información de los sensores
2016-03-12 archivo listo para corte laser
    [caja_design_laser.dwg]
2016-03-12 Archivo impresión laser actualizado
    [caja_design_laser.dwg]
2016-03-12 actualizado archivo impresión corte laser
    [caja_design_laser.dwg]
2016-03-12 Versión mejorada de la caja
    - QR Vectorizado de otra fuente
    - Entrada alimentación auxiliar añadida
    - Sistema de unión dentada añadido
2016-03-12 .dxf añadido
    [caja_design_v2.dxf]
2016-03-12 Eliminados los Grupos de los archivos de diseño
    [caja_design_v2.dxf]
2016-03-13 Actualizando los Archivos para el corte laser
    [caja_design.dwg, caja_design.dxf, caja_design_laser.dwg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]
2016-03-21 Slip Temperatura y humedad
    - Librería DHT añadida en /librerias
    - Ejemplo incluido en /snippets
    - README.md actualizado
    [temperatura_y_humedad.ino]
2016-03-21 Snipp añadido - Temperatura y Humedad en formato JSON
2016-03-21 snippets de temperatura/humedad movidos y actualizados
2016-03-21 Demo NODE.js lectura temperatura y humedad añadido
2016-03-21 Programa principal subido
    Includo:
    - Soporte JSON
    - Datos Humedad y Temperatura
    - Datos MQ-3
    - Valores digitales (umbrales)
    Pendiente:
    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
2016-03-22 Nuevo ejemplo añadido a la condimentación
2016-03-22 Ecuación cálculo de alcohol actualizada
2016-03-22 Ecuación cálculo Monóxido de Carbono añadida
    - Gráfico
    - Documentación en /calculos
    - Actualizado Sketch principal
2016-03-22 Monóxido de Carbono fórmula reajustada
2016-03-23 Ecuación cálculo Dióxido de Carbono añadida
    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
2016-03-23 Ecuación cálculo Óxidos de Nitrógeno añadida
    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
2019-03-08 STL separados para impresoras 3D pequeñas
    [caja_design (extracted) 1.stl, caja_design (extracted) 2.stl, caja_design (extracted) 3.stl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]
2019-03-08 gcode para impresion 3D en ender 3
2019-07-04 fix: snippets/temperatura y humedad/.snyk & snippets/temperatura y humedad/package.json to reduce vulnerabilities
    The following vulnerabilities are fixed with a Snyk patch:
    - https://snyk.io/vuln/SNYK-JS-LODASH-450202
